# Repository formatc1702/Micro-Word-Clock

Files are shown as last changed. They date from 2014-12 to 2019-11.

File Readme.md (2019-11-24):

# Micro Word Clock v2

## Description
A tiny replica of the famous Word Clock, using only an ATmega microcontroller, a DS1307 Real Time Clock and a few passive components to display the time on an 8x8 LED matrix. The letters have been printed onto a transparent sheet and glued over the LEDs to produce a readable time.
See the YouTube video [here](https://www.youtube.com/watch?v=9ko9CeylUTs).

## Directory structure
- **MicroWordClock2-Arduino** contains the firmware, including pin definitions for the LED matrix and location of the words in each language.
- **EAGLE** contains the schematic and PCB design files for the proejct.
- **Graphics** contains the design for the transparency sheet to place over the LED matrix to form the words, designed in Inkscape. Contributions in more languages are welcome!

## Bill of Materials

| | Part name | Package size | [Reichelt](http://reichelt.de) part number |
|---|---|---|---|
| IC1 | ATmega328P-AU | TQFP-32 | ATMEGA 328P-AU |
| IC2 | DS1307Z+ | SO-8 | DS 1307Z |
| C1 | 220nF ceramic | 2012 metric / 0805 imperial  | X7R-G0805 0,22µ |
| C2 | 2.2uF tantalum | 3528 metric / B-case | SMD TAN.2,2/20 |
| S1 | SMD push button | 6.2x6.5mm | TASTER 9314 |
| XTAL | 32.768 kHz crystal | 3216 metric / 1206 imperial  | 32,768 CC7V-12,5 |
| LED matrix | 8x8 matrix | 20x20mm | [GYXM-788ASR](http://eud.dx.com/product/lson-788-8-x-8-red-led-display-dot-matrix-module-black-white-844302671)* (DealExtreme) |
| PCB | | 20x20mm | [OshPark](https://oshpark.com/shared_projects/NkANAgow) |
\* Probably any LED matrix labeled 788 should work.

You will require an In-System Programmer (ISP) to write the firmware onto the microcontroller.

## Burning the bootloader and uploading the sketch
Please read these two tutorials if you are unfamiliar with burning a bootloader:
- http://arduino.cc/en/Tutorial/ArduinoISP
- http://arduino.cc/en/Tutorial/ArduinoToBreadboard

The required procedure is the one described as "AVR on a breadboard" and "Minimal circuit", respectively, as there is no external crystal attached to the microcontroller.

Please download Carlos Rodrigues' Barebones ATmega Chips board configuration file:
https://github.com/carlosefr/atmega (instructions inside)

The ICSP header on the Micro Word Clock PCB is the standard layout described [here](http://www.atmel.com/images/doc0943.pdf) (Fig. 2).

## Contributions
Carl Monk has built [his own version](http://fortoffee.org.uk/2014/12/word-clock-with-a-unicorn/) using a [Unicorn HAT](http://shop.pimoroni.com/products/unicorn-hat).

[quistoph](https://github.com/qistoph) has made a Dutch layout.

Tanguy Rewers independently came up with an alternative Dutch layout (labeled as dutch2).

## Featured on
- [Hackaday](http://hackaday.com/2014/11/29/micro-word-clock/)
- [Gizmodo](http://gizmodo.com/build-a-tiny-version-of-those-pricey-word-clocks-on-the-1665134624)
- [The Atmel Blog](http://blog.atmel.com/2014/12/01/build-your-own-micro-word-clock-with-an-atmega328p/)

## License
This project (both software and hardware) is published under a [Creative Commons BY-SA 3.0 License](http://creativecommons.org/licenses/by-sa/3.0/).

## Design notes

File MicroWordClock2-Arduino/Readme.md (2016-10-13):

Please read the notes in the [parent folder](https://github.com/formatc1702/Micro-Word-Clock/tree/master).

The RTClib.cpp and RTClib.h files can be placed into your Arduino sketchbooks's library/ folder for use in other projects as well.

Please download Carlos Rodrigues' Barebones ATmega Chips board configuration file:
https://github.com/carlosefr/atmega (instructions inside)

The boards.txt file is not needed for newer Arduino IDE versions that include the Boards Manager (under Tools -> Board).

For old versions of the Arduino IDE, it should be placed into a subfolder inside the hardware/ folder of your Arduino sketchbook. E.g. hardware/barebones/boards.txt.

RTClib code by [JeeLabs](http://jeelabs.org) released to the public domain.

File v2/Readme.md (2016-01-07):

#Micro Word Clock v2

##Description
A tiny replica of the famous Word Clock, using only an ATmega microcontroller, a DS1307 Real Time Clock and a few passive components to display the time on an 8x8 LED matrix. The letters have been printed onto a transparent sheet and glued over the LEDs to produce a readable time.
See the YouTube video [here](https://www.youtube.com/watch?v=9ko9CeylUTs).

##Directory structure
- **Arduino** contains the firmware, including pin definitions for the LED matrix and location of the words in each language.
- **EAGLE** contains the schematic and PCB design files for the proejct.
- **Graphics** contains the design for the transparency sheet to place over the LED matrix to form the words, designed in Inkscape. Contributions in more languages are welcome!

##Bill of Materials
Includes part numbers for German supplier [Reichelt](www.reichelt.de)
- IC1: ATmega328P-AU (TQFP-32 package) Reichelt code: ATMEGA 328P-AU
- IC2: DS1307Z+ (SO-8 package) Reichelt code: DS 1307Z
- C1: 220nF ceramic (2012 metric size, 0805 imperial size) Reichelt code: X7R-G0805 0,22µ
- C2: 2.2uF tantalum (3528 metric size, B-case) Reichelt code: SMD TAN.2,2/20
- S1: 6.2x6.5mm SMD push button. Reichelt code: TASTER 9314
- XTAL: 32.768 kHz crystal (3216 metric size, 1206 imperial size) Reichelt code: 32,768 CC7V-12,5
- LED matrix: [GYXM-788ASR](http://eud.dx.com/product/lson-788-8-x-8-red-led-display-dot-matrix-module-black-white-844302671) 20x20mm 8x8 LED matrix. Probably any matrix labeled 788 should work.
- PCB: [OshPark](https://oshpark.com/shared_projects/NkANAgow)

You will require an In-System Programmer (ISP) to write the firmware onto the microcontroller.

##Burning the bootloader and uploading the sketch
Please read these two tutorials if you are unfamiliar with burning a bootloader:
- http://arduino.cc/en/Tutorial/ArduinoISP
- http://arduino.cc/en/Tutorial/ArduinoToBreadboard
 
The required procedure is the one described as "AVR on a breadboard" and "Minimal circuit", respectively, as there is no external crystal attached to the microcontroller.

The ICSP header on the Micro Word Clock PCB is the standard layout described [here](http://www.atmel.com/images/doc0943.pdf) (Fig. 2). 

##Contributions
Carl Monk has built [his own version](http://fortoffee.org.uk/2014/12/word-clock-with-a-unicorn/) using a [Unicorn HAT](http://shop.pimoroni.com/products/unicorn-hat).

[quistoph](https://github.com/qistoph) has made a Dutch layout.

Tanguy Rewers independently came up with an alternative Dutch layout (labeled as dutch2).

##Featured on
- [Hackaday](http://hackaday.com/2014/11/29/micro-word-clock/)
- [Gizmodo](http://gizmodo.com/build-a-tiny-version-of-those-pricey-word-clocks-on-the-1665134624)
- [The Atmel Blog](http://blog.atmel.com/2014/12/01/build-your-own-micro-word-clock-with-an-atmega328p/)

##License
This project (both software and hardware) is published under a [Creative Commons BY-SA 3.0 License](http://creativecommons.org/licenses/by-sa/3.0/).

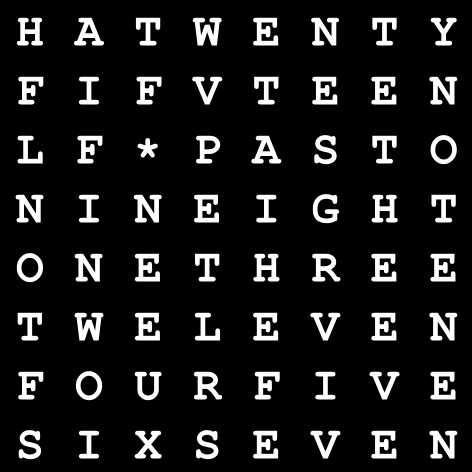
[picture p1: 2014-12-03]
Graphics/English 20x20mm.png

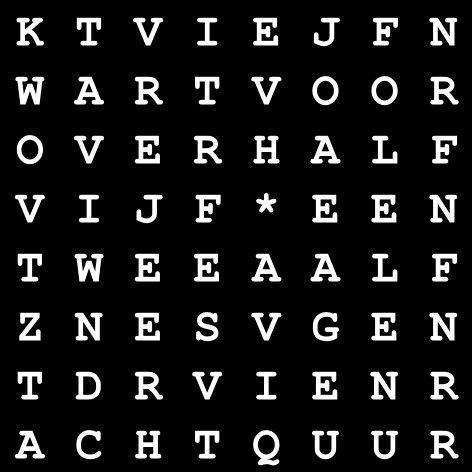
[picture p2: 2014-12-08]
Graphics/Dutch 20x20mm.png

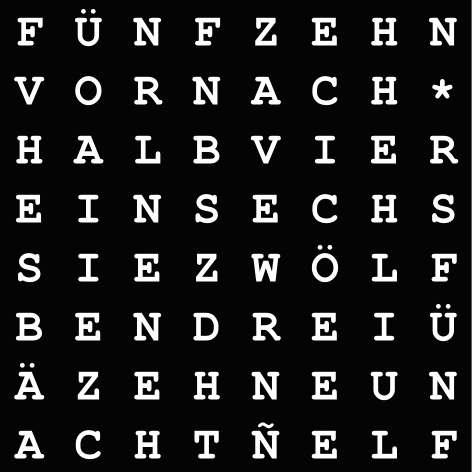
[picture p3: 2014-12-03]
Graphics/German 20x20mm.png

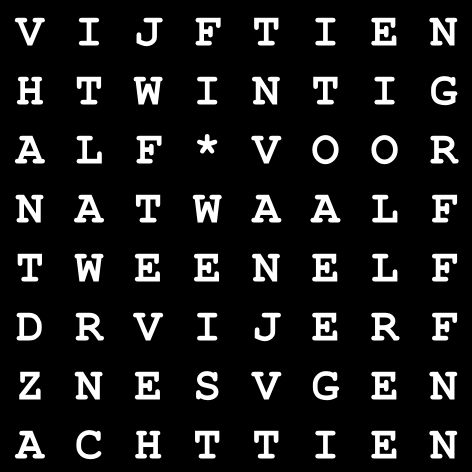
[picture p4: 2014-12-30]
Graphics/Dutch2 20x20mm.png

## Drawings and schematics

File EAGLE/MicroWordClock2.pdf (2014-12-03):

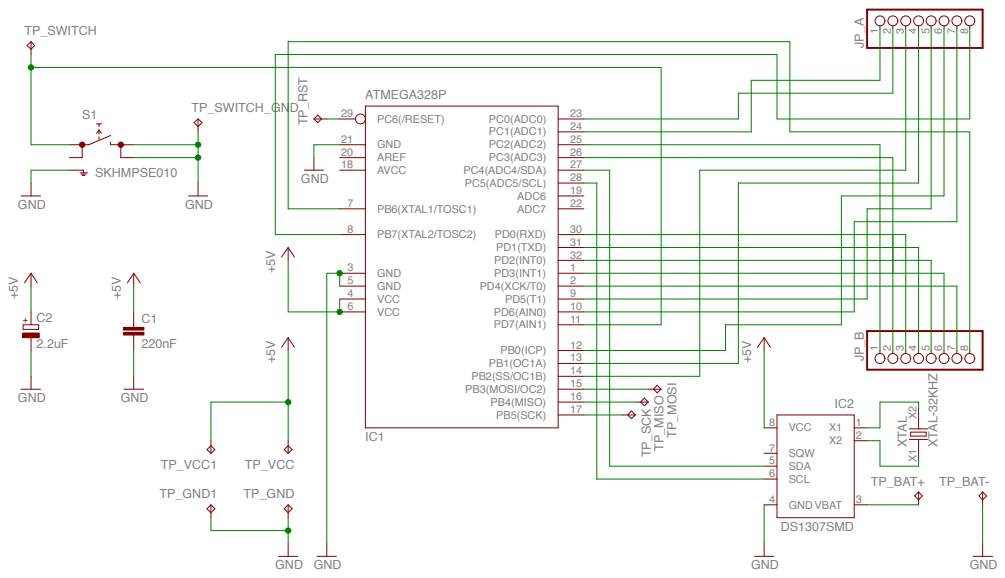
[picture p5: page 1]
ATMEGA328P; DS1307SMD; GND; GND XTAL⁻32KHZ; SKHMPSE010; GND +5V; PB5(SCK); PB7(XTAL2/TOSC2) 8; PB6(XTAL1/TOSC1) 7; GND 3 GND 5 VCC 4 VCC 6; GND 21 AREF 20 AVCC 18; PB4(MISO); 16 PB3(MOSI/OC2); 13 PB0(ICP); PD7(AIN1); 11 PD6(AIN0); 9 PD4(XCK/T0); 2 PD3(INT1); 1 PD2(INT0); 32 PD1(TXD); 31 PD0(RXD); ADC7; 22 ADC6; 19 PC5(ADC5/SCL); 28 PC4(ADC4/SDA); 27 PC3(ADC3); 26 PC2(ADC2); 25 PC1(ADC1); 24 PC0(ADC0); 23 PC6(/RESET) 29; TP_SCK; TP_MISO; TP_RST; SDA 5; VBAT; VCC 8; GND 4; SCL 6; SQW 7; TP_VCC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

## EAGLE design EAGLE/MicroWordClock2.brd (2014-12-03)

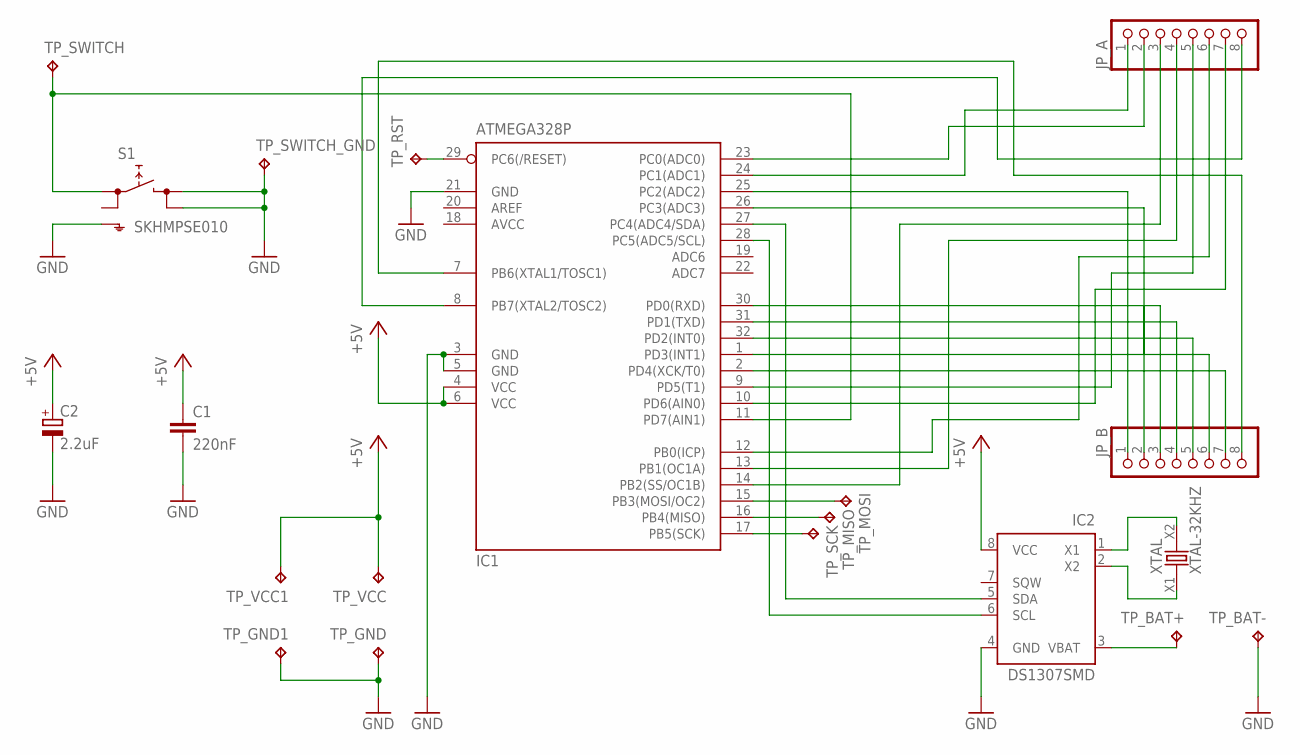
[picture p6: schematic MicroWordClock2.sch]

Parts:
C1: 220nF; C0805
C2: 2.2uF; B/3528-21R
IC1: ATMEGA328P; TQFP32-08
IC2: DS1307SMD; SO-08M
JP_A: PINHD-1X8CLEANBIG; 1X08-CLEANBIG
JP_B: PINHD-1X8CLEANBIG; 1X08-CLEANBIG
S1: SKHMPSE010; SKHMPXE010
TP_BAT+: TPB2,54; B2,54
TP_BAT-: TPB2,54; B2,54
TP_GND: TPB1,27; B1,27
TP_GND1: TPB2,54; B2,54
TP_MISO: TPB1,27; B1,27
TP_MOSI: TPB1,27; B1,27
TP_RST: TPB1,27; B1,27
TP_SCK: TPB1,27; B1,27
TP_SWITCH: TPB1,27; B1,27
TP_SWITCH_GND: TPB1,27; B1,27
TP_VCC: TPB1,27; B1,27
TP_VCC1: TPB2,54; B2,54
XTAL: XTAL-32KHZ; XTAL-SMD-1206-3216M

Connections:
+5V: C1.1, C2.+, IC1.4 (VCC), IC1.6 (VCC), IC2.8 (VCC), TP_VCC.TP, TP_VCC1.TP
A1: IC1.24 (PC1(ADC1)), JP_A.1
A2: IC1.23 (PC0(ADC0)), JP_A.2
A3: IC1.14 (PB2(SS/OC1B)), JP_A.3
A4: IC1.13 (PB1(OC1A)), JP_A.4
A5: IC1.9 (PD5(T1)), JP_A.5
A6: IC1.12 (PB0(ICP)), JP_A.6
A7: IC1.10 (PD6(AIN0)), JP_A.7
A8: IC1.8 (PB7(XTAL2/TOSC2)), JP_A.8
AVCC: IC1.18 (AVCC)
B1: IC1.25 (PC2(ADC2)), JP_B.1
B2: IC1.26 (PC3(ADC3)), JP_B.2
B3: IC1.30 (PD0(RXD)), JP_B.3
B4: IC1.31 (PD1(TXD)), JP_B.4
B5: IC1.32 (PD2(INT0)), JP_B.5
B6: IC1.1 (PD3(INT1)), JP_B.6
B7: IC1.2 (PD4(XCK/T0)), JP_B.7
B8: IC1.7 (PB6(XTAL1/TOSC1)), JP_B.8
GND: C1.2, C2.-, IC1.3 (GND), IC1.5 (GND), IC1.21 (GND), IC2.4 (GND), S1.3 (2.1), S1.4 (2.2), S1.5 (SH), TP_BAT-.TP, TP_GND.TP, TP_GND1.TP, TP_SWITCH_GND.TP
MISO: IC1.16 (PB4(MISO)), TP_MISO.TP
MOSI: IC1.15 (PB3(MOSI/OC2)), TP_MOSI.TP
unnamed: IC2.2 (X2), XTAL.X1
unnamed: IC2.1 (X1), XTAL.X2
unnamed: IC1.28 (PC5(ADC5/SCL)), IC2.6 (SCL)
RESET: IC1.29 (PC6(/RESET)), TP_RST.TP
SCK: IC1.17 (PB5(SCK)), TP_SCK.TP
SDA: IC1.27 (PC4(ADC4/SDA)), IC2.5 (SDA)
SWITCH: IC1.11 (PD7(AIN1)), S1.1 (1.1), TP_SWITCH.TP
VBAT: IC2.3 (VBAT), TP_BAT+.TP

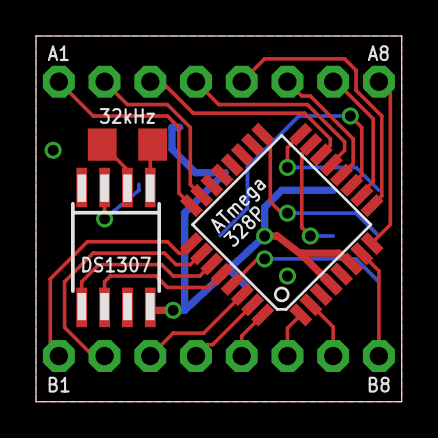
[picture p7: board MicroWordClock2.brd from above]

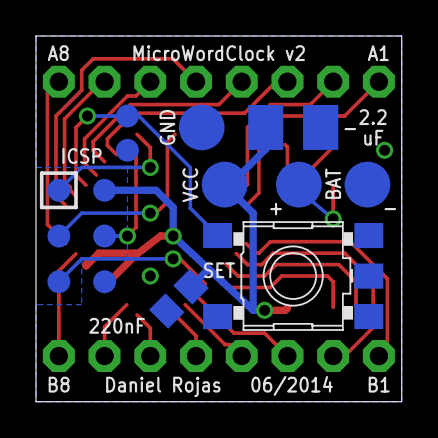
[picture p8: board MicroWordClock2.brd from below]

Board: 2 copper layers, 20.3 x 20.3 mm, 20 parts (15 on the bottom side), 28 nets.

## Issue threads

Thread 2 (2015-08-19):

English Layout

jkDesignDE, 2015-08-19:
Very nice project!
It inspired me to build my own 8x8 matrix clock. The only what disturbed me on your design is that some words are interrupted or broken. So I wrote a C program to find all word combinations in a matrix.
This is my favorite English version:
TWENTYQR
EHALFIVE
N*JPASTO
SSKTWONE
EIGHTFIF
VXTREINO
ETWELVEU
NELEVENR
The only compromise is the abbreviations for “QUARTER” -> “QR”.
Feel free to use this in your word clock project.

P.S. For the German version I found over 1600 solutions without interrupts, breaks or abbreviations
-JK-

PabluskiNC, 2015-08-19:
Jochen,

Hello from North Carolina in USA.

I also took the Micro Word Clock and made my own: http://pablo-sanchez.com/8x8-word-clock-with-rtc/

I used a bigger (6cm x 6cm) LED matrix, however. I also added a real time clock to the project.

I altered the code so that it allows the clock to have multiple languages built in. You can set the language by holding down the button when it is powered up. I have not published my changes yet, but I can share them with you for testing.

Also, would you share your C program? I was using a spreadsheet to find combinations and to create the needed maps.

-Pablo Sanchez

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

formatc1702, 2015-10-06:
Hello Jochen and PabluskiNC!

Thanks a lot for your contributions! Sorry for the late reply.
Unfortunately, I do not have the time to properly add your layouts to the repo myself at this time.
I kindly invite you to add them yourself if you wish! :)

I guess you already know, but I would need the <language>.c file in the Arduino folder, as well as a corresponding .svg and .png for the Graphics folder. You can of course add your entry to the 'Contributions' section of the Readme.md

:-)

dglaude, 2016-05-31:
I am searching for a French Layout. Someone named Pablo Sanchez says he made one, but I did not find a picture/description of it.

I builded a French layout (actually a few), but they require two separate display (in sequence), one for the hour, and on for the hour modifier. I see no other way on 8x8:

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

Please contact me if you have a better/other layout.

Thanks

PabluskiNC, 2016-05-31:
Hello David,

Here’s what I have. I hope it helps.

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

phana007, 2017-08-03:
Hi all, I'm having a problem with my word clock not progressing forward in time. Everything works as it should be seconds flashing. I can progress it forward in time manually but over five minutes goes past and it still sits at the same time.

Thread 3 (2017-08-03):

Not going forward in time

phana007, 2017-08-03:
Hi all, I'm having a problem with my word clock not progressing forward in time. Everything works as it should be seconds flashing. I can progress it forward in time manually but over five minutes goes past and it still sits at the same time.

PabluskiNC, 2017-08-03:
Are you sure that your RTC is functioning?
Maybe test it: https://learn.adafruit.com/ds1307-real-time-clock-breakout-board-kit/understanding-the-code

phana007, 2017-08-03:
Hi, I might have got the orientation wrong on my DS1307Z+. There is a small indent on the chip, but can't see it in other peoples build pictures.

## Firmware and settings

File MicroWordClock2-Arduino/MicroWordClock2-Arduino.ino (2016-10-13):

// Libraries
#include <Wire.h>
#include "RTClib.h"

// Local includes
#include "pindefs.h"
#include "otherdefs.h"

// Customizable options
#include "english.h" // exchange this for the language you need
boolean blink_enable = true;
boolean blinknow = false;
#define FREQ_DISPLAY 1000 // Hz
#define FREQ_TIMEUPDATE 2 // Hz
//unsigned long check_interval = 500; // time update rate
//#define refresh_rate 2560 // display refresh rate in microseconds

volatile int cols[]={ // PC0,PD4,PB6!,PB3,PD5,PB4,PC2,PC3
  MTX_COL1,MTX_COL2,MTX_COL3,MTX_COL4,MTX_COL5,MTX_COL6,MTX_COL7,MTX_COL8}; // ON=LOW
volatile int rows[]={ // PB2,PC1,PD7,PB5,PD2,PD6,PD3,PB7!
  MTX_ROW1,MTX_ROW2,MTX_ROW3,MTX_ROW4,MTX_ROW5,MTX_ROW6,MTX_ROW7,MTX_ROW8}; // ON=HIGH

enum ClockMode {
  NORMAL,
  SET_MIN,
  SET_HRS,
  END,
};
ClockMode clockmode = NORMAL;

volatile char disp[8]={
  0B11111111,
  0B11111111,
  0B11111111,
  0B11111111,
  0B11111111,
  0B11111111,
  0B11111111,
  0B11111111,
};

char testdisp[8]={
  0B11111111,
  0B11111111,
  0B11111111,
  0B11111111,
  0B11111111,
  0B11111111,
  0B11111111,
  0B11111111,
};

// RTC stuff
RTC_DS1307 rtc;
unsigned long disp_sec;
unsigned long disp_min;
unsigned long disp_hrs;

volatile boolean updatenow = false;

boolean buttonState = LOW;
unsigned long buttonMillis = 0;
boolean buttonHandled = true;

void loop() {
  if(updatenow) {
    updateTime();
    prepareDisplay();
    updatenow = false;
  }

  if(digitalRead(PIN_BUTTON) != buttonState) {
    buttonState = digitalRead(PIN_BUTTON);
    if(buttonState == LOW) { // button was pressed
      buttonMillis = millis();
      buttonHandled = false;
    }
    else { // button was released
      buttonHandled = true;
      unsigned long buttonDelay = millis() - buttonMillis;
      if(buttonDelay > 100) { // debounce
        if(buttonDelay < 1000) { // simple press
          updatenow = true;
          switch(clockmode) {
          case NORMAL:
            blink_enable = !blink_enable;
            blinknow = true;
            TCNT1 = 0;
            break;
          case SET_MIN:
            rtc.adjust(rtc.now().unixtime() + 1*60);
            blinknow = true;
            TCNT1 = 0;
            break;
          case SET_HRS:
            rtc.adjust(rtc.now().unixtime() + 1*60*60);
            blinknow = true;
            TCNT1 = 0;
            break;
          }
        }
      }
    }
  }
  else {
    if(buttonState == LOW && !buttonHandled) { // button is being pressed
      unsigned long buttonDelay = millis() - buttonMillis;
      if(buttonDelay > 2000) {
        blinknow = false;
        TCNT1 = 0;
        clockmode = (ClockMode)((int)clockmode + 1);
        if(clockmode == END)
          clockmode = NORMAL;
        buttonHandled = true;
        updatenow = true;
      }
    }
  }
}

void updateTime() {
  // Adjust 2.5 minutes = 150 seconds forward
  // So at 12:03 it already reads "five past 12"
  DateTime now = rtc.now().unixtime() + 150;

  disp_sec = now.second();
  disp_min = now.minute();
  disp_hrs = now.hour();

  disp_min /= 5;

  if(disp_min >= min_offset)
    ++disp_hrs %= 12;
  else
    disp_hrs   %= 12;
}

void prepareDisplay() {
  blinknow = !blinknow;
  FOR_ALLROWS {
    disp[r]=B00000000;
    FOR_ALLCOLS {
      if((clockmode != SET_MIN || !blinknow))
        disp[r] |= minutes[disp_min][r] & (B10000000 >> c);
      if((clockmode != SET_HRS || !blinknow))
        disp[r] |= hours  [disp_hrs][r] & (B10000000 >> c);
      if(clockmode == NORMAL && blink_enable && !blinknow)
        disp[r] |= blinky[r];
    }
  }
}

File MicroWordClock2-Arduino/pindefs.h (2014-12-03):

// Matching LED rows/columns to the matrix's pins
// to microcontroller ports to microcontroller pins
// to Arduino pin notation. Whew.

// PORTB: Digital pins (offset 8), PB6/PB7 are XTAL
// PORTC: Analog pins (no offset), PC6 is RESET, PC7 nonexistent
// PORTD: Digital pins (no offset)

// Pin definitions
#define PIN_BUTTON PD7

// Mapping Matrix Row/Col numbers to Matrix pins
#define MTX_ROW1 MTX_PIN9
#define MTX_ROW2 MTX_PIN14
#define MTX_ROW3 MTX_PIN8
#define MTX_ROW4 MTX_PIN12
#define MTX_ROW5 MTX_PIN1
#define MTX_ROW6 MTX_PIN7
#define MTX_ROW7 MTX_PIN2
#define MTX_ROW8 MTX_PIN5

#define MTX_COL1 MTX_PIN13
#define MTX_COL2 MTX_PIN3
#define MTX_COL3 MTX_PIN4
#define MTX_COL4 MTX_PIN10
#define MTX_COL5 MTX_PIN6
#define MTX_COL6 MTX_PIN11
#define MTX_COL7 MTX_PIN15
#define MTX_COL8 MTX_PIN16

#define MTX_PIN1  SIG_B1
#define MTX_PIN2  SIG_B2
#define MTX_PIN3  SIG_B3
#define MTX_PIN4  SIG_B4
#define MTX_PIN5  SIG_B5
#define MTX_PIN6  SIG_B6
#define MTX_PIN7  SIG_B7
#define MTX_PIN8  SIG_B8
#define MTX_PIN9  SIG_A8
#define MTX_PIN10 SIG_A7
#define MTX_PIN11 SIG_A6
#define MTX_PIN12 SIG_A5
#define MTX_PIN13 SIG_A4
#define MTX_PIN14 SIG_A3
#define MTX_PIN15 SIG_A2
#define MTX_PIN16 SIG_A1

#define SIG_A1  PC1
#define SIG_A2  PC0
#define SIG_A3  PB2
#define SIG_A4  PB1
#define SIG_A5  PD5
#define SIG_A6  PB0
#define SIG_A7  PD6
#define SIG_A8  PB7
#define SIG_B1  PC2
#define SIG_B2  PC3
#define SIG_B3  PD0
#define SIG_B4  PD1
#define SIG_B5  PD2
#define SIG_B6  PD3
#define SIG_B7  PD4
#define SIG_B8  PB6

#define PB0  8
#define PB1  9
#define PB2 10
#define PB3 11
#define PB4 12
#define PB5 13
#define PB6 A6 //XTAL1
#define PB7 A7 //XTAL2

#define PC0 A0
#define PC1 A1
#define PC2 A2
#define PC3 A3
#define PC4 A4
#define PC5 A5


#define PD0 0
#define PD1 1
#define PD2 2
#define PD3 3
#define PD4 4
#define PD5 5
#define PD6 6
#define PD7 7

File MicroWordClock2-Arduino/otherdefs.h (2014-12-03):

// LED matrix pin control
#define FOR_ALLCOLS for(int c=0;c<8;c++)
#define FOR_ALLROWS for(int r=0;r<8;r++) 
#define COL_OFF HIGH
#define COL_ON LOW
#define ROW_OFF LOW
#define ROW_ON HIGH
// Refresh rate for each row
#define row_rate refresh_rate/8
#define pixel_rate row_rate/8

//  (sysclock) / (freq*prescaler)
#define SYSCLOCK 8000000 // Hz
#define PRESCALER0 64
#define T0_COMPARE SYSCLOCK / (FREQ_DISPLAY * PRESCALER0)

#define PRESCALER1 64
#define T1_COMPARE SYSCLOCK / (FREQ_TIMEUPDATE * PRESCALER1)

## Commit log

2014-12-03 Initial upload of files
    [MicroWordClock2.brd, MicroWordClock2.sch]
2014-12-08 Added boards.txt
2015-12-07 Added Gerber Files
2016-10-13 Reorder files and update Readme.
    [MicroWordClock2.brd, MicroWordClock2.sch]
2016-10-13 Improve BOM
